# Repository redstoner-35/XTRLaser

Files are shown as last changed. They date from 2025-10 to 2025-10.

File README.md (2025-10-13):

powered by 35's Embedded Systems Inc. A Next generation Driver Solution for Portable Ultra high Output Laser Pointer                                                                                                                     

### 概述

Xtern Ripper Laser Edition(简称XTRLaser)是专用于驱动日亚LD BANK **（例如NUBB23、NUBB33以及NUBB27、NUBB37等）** 的高能效侧按电子开关控制的升压恒流驱动器。该驱动器具备自适应功能，同时支持单锂和双锂输入并自动适配采用最合适的功率驱动激光模组。该驱动的尺寸为22mm，高度7mm，可以完美兼容东东海D2GC或M0AC等22mm驱动位的侧按小直外壳。在M0AC小直内搭配日亚NUBB23模块时可以实现高达31W的峰值光功率并且稳定运行至温度保护激活。是实现小体积暴脾气亮骚烧东西激光小直的专用解决方案。相比市面上基于LED手电筒驱动的魔改产物具有更高的耐压（高达25V Rated可以适配20V工作电压的五管LD Bank） **（例如那些基于MP3431芯片单双锂输入通用升压手电驱动改反馈电阻做的LD驱动，芯片容许的最高输出电压为16V然后NUBB33类的四管激光模块的Vf高达15.98V，长期顶着芯片的输出耐压极限跑就不怕炸管么？）** 和稳定性以及更适配和更智能的温度保护和操作逻辑（一键点动烧灼模式，自动锁定等）。

### 性能数据

+ 支持的电池输入类型：1S至2S的三元锂电池组，2S电池组的总交流内阻需小于50mΩ且额定放电能力大于等于15A。 **注意：驱动在1S模式下将会自动限制输出功率至约30W避免IC过载，但是此时仍然需要使用全极耳类型的低内阻动力电池，放电能力应大于20A且交流内阻小于8mΩ。如果需要获得完整的使用体验，请搭配2S电池组使用！**
+ 支持的LD Bank类型：（单/双锂）NUBB13、NUBB23、NUBB33 **NUBB27和NUBB37硬件理论支持，但是需要调整参数请参考下方的内容** 。（仅单锂并搭配特定固件和硬件）NURM11T，具体请前往下方的LD Bank类型章节查看。
+ 支持的LD电流：150mA至4.1A（适配单管多串LD）
+ 温度保护：46度多阶变值PI环+常亮预测算法实现的自适应外壳恒温（温控启动后驱动根据外壳散热能力和环境自动调整LD的亮度达到最高可实现的亮度，充分利用外壳的散热能力和热容）+55度极亮cutoff（强制退出极亮并返回到低亮）+65度强制关机三段式温度保护。**相比那些温度一到就给你拉闸不给开机的断崖式温度保护极大提高了用户的使用体验。都5202年了还没有一个能实现自适应恒温的激光驱动，属实是扯蛋。**
+ 电池保护：具有欠压自动降档和关机保护以及过电压保护
+ 输出保护：具备LD开路和短路检测

### 输出效率

目前该驱动已进行了输出效率的初步测试，结果如下：

+ 双锂模式驱动NUBB23（全功率）：`输入：7.4V*9.5A=70.3W，输出15.99V*4.21A=67.3179W` 此时典型效率约96.01%，损耗2.98W
+ 单锂模式驱动NUBB23（半功率）：`输入：3.53V*8.90A=31.417W，输出14.93V*1.91A=28.5163W` 此时典型效率约90.76%，损耗2.90W

受限于较低的工作频率所需的4R7电感导致DCR发热损耗较大使得在单锂工作时效率不好看。不过该效率对于输出耐压支持20V LD Bank的专用22mm驱动而言仍然处于优秀水平，不需要担心在壳子内过热而无法工作。

### 自动锁定功能说明

考虑到该类激光手电具有极高的输出功率，当用户长时间静置未用，并且在某天突然拿起时会因为忘记手电处于何种状态并误开启高功率模式造成严重的安全事故。**激光贴吧之前就有因为熊孩子误拿起长期静置且未处于锁定模式的大功率激光手电并且未做任何防护的情况下意外开启造成眼睛永久失明的案例！！** 因此该驱动固件具备自动锁定功能，当手电检测到用户长时间未使用并静置超过20分钟后，驱动将会自动进入锁定模式并且重置挡位记忆到最低挡位确保安全。进入锁定模式后即使重新安装电池也无法解锁，此时用户需要参考下方章节关于按键锁的内容，手动解锁手电后手电才会恢复正常使用状态。且解锁手电后，首次单击开机时手电会固定进入低挡位以确保安全使用，用户可以自行换挡。

### 基本功能操作逻辑

+ 调焦挡位：关机状态下单击+长按进入。该挡位下驱动会令LD在远低于其阈值电流的条件下运行输出无害的弱光用于进行光学系统测试或者对焦以及瞄准工作（也可以拿来逗猫玩 *笑）。该挡位下用户可以单击关闭，若长按则会进入到循环挡位模式的最低挡位。
+ 循环挡位模式：关机状态下单击进入。首次上电时驱动默认位于最低挡位，长按在`低->中->中高->高`四个挡位内反复循环切换。单击+长按则逆向按照`高->中高->中->低`的顺序逐步降到最低并在最低挡位停止，单击关闭。**注意：如果驱动被配置为单锂电模式，则驱动的高挡位将会被禁用，此时循环只剩下：低、中和中高挡位。**
+ 无极调光模式：关机状态下长按进入。该挡位允许用户在0.4A至3A（对应0.5-22W光功率）的范围内无极调整并选定一个指定的亮度挡位（如果驱动工作在单锂模式，则调节范围将会被限制为0.4-1.8A对于0.5-12W光功率）。进入该挡位后长按升高亮度，单击+长按减少亮度。若亮度达到最高或最低时驱动会令LD慢闪提示您亮度调整已经达到限制。若要回到关机状态，则单击开关一次。 **注：该挡位的亮度数据具有永久性记忆，设定好亮度后约3秒系统会永久保存至存储器内，即使断电也不会丢失。**
+ 极亮挡位：任意状态下双击进入。如果您只安装了一节电池，则双击会进入到循环挡位中的中高档此时仍然能一键进入循环档中的最高功率（1.8A电流，对应12W光功率）模拟双击极亮的行为，**但是无法开启需要双锂的真正全功率极亮。** 如果您安装了2节电池，则此时驱动将会以全功率输出并实现约31W的光功率。 **该挡位发热巨大且输出功率极高，为了避免引起火灾请务必小心使用！**
+ 特殊功能挡位：关机状态下三击进入，长按在`SOS->呼吸巡航灯->周期频闪信标灯`这三种特殊模式内按顺序循环切换。单击+长按则逆序循环切换。单击回到关机状态。对于这三个特殊功能挡位的具体功能则如下所示：
  - SOS：驱动令LD以0.8A电流点亮播报国际标准SOS求救信号（三短三长三短）并反复循环。每次播报结束后会停顿三秒再继续。
  - 呼吸巡航灯：驱动令LD工作在呼吸闪状态（亮度从低缓升最高后又缓降到最低，到最低后熄灭并停顿三秒后再次从最低亮度缓升并反复循环）
  - 周期频闪信标灯：进入后驱动首先以低亮度点亮LD约2秒提醒用户已经进入该模式。然后驱动每隔3秒令LD以额定功率短时间脉冲工作（约50mS）后立即关闭并进入休眠，3秒后再次启动输出脉冲并反复循环。 
+ 一键烧灼模式：关机状态下四击开关，此时驱动以远低于激光管阈值电流的最低功率点亮输出无害的弱光方便用户进行瞄准，按住开关则驱动立即以全功率工作（此时约30W光功率，如果驱动工作在单锂模式则限制为约12W）进行烧灼，松开则回到低功率状态。若用户单击则回到关闭状态。该挡位具备超时和过温保护功能。若驱动电量不足或超过1分钟未操作，以及驱动发生过热事件，则会自动关机。
+ 按键锁：关机状态下五击开关，侧按指示灯红色闪三次进入锁定模式。进入锁定模式后，除了单击+长按临时开启几乎无害的低功率激光输出，松开手自动熄灭或开启20秒后自动熄灭以外（模拟人畜无害的低功率沙盘指星笔的行为，用于骗过安检），其余任何操作均会被驱动忽略并使用红色快闪5次提示用户。**为了保证安全，进入锁定模式后即使重新安装电池，激光手电也会始终保持在锁定状态。** 在锁定状态下再次五击，侧按指示灯绿色闪烁三次，并且LD以低功率点亮0.5秒表示成功解锁，此时驱动回到正常操作模式可以正常操作。

### 特殊功能操作逻辑

+ 应急求救挡位：关机状态下五击+长按进入，驱动令LD以0.6A电流点亮播报国际标准SOS求救信号（三短三长三短）并反复循环。每次播报结束后会停顿三秒再继续。该挡位只要电池在静置状态下电压高于2.5V就会持续运行并一直发送信号，可以让用户在紧急情况下以报废电池的小小代价持续的发射求救信号并获得一线生机。 **对于非紧急状态不建议使用该挡位，以免电池过度放电并永久损毁。**
+ 重置无极调光亮度：在关机状态下四击+长按，驱动将会重置无极调光亮度至最低值并进入无极调光模式，其余操作请参考基本功能章节内的无极调光操作指引。
+ 固件编译时间戳查询：关机状态下8击进入。进入后驱动将会令LD点亮1秒，提示即将开始播报。然后驱动将会按顺序播报固件编译的年份、月份，日期以及编译时的时间（精确到分钟）。首先驱动会播报固件编译的具体日期，播报会分为三组数字，每组数字之间停顿2.5秒，同一组数字之间会有1.5秒的间隔方便用户区分。在播报完第一到第三组数字所表示的驱动编译固件编译的年份、月份，日期之后，驱动将会停顿4.5秒然后开始播报固件编译的具体时间（精确到分钟）。具体编译时间的播报会分为两组数字，每组数字之间停顿2.5秒，同一组数字之间会有1.5秒的间隔方便用户区分。**需要注意的是，播报启动后就无法中断，在版本信息播报过程中，驱动将不响应任何操作，直到播报结束。** 详细的播报规则如下：
 
  - 第一组数字：指示固件编译的年份。其中LD慢速闪烁N次表示非零的数字，如果快速闪烁一次，则表示该数据位为0。两位数字之间系统会停顿1.5秒。例如`慢闪2次-停顿1.5秒-慢闪5次`表示固件编译的年份为**25（2025年）**。
  - 第二组数字：指示固件编译的月份。其中LD慢速闪烁N次表示非零的数字，如果快速闪烁一次，则表示该数据位为0。两位数字之间系统会停顿1.5秒。例如`快闪1次-停顿1.5秒-慢闪9次`表示固件编译的月份为**09（9月）**。
  - 第三组数字：指示固件编译的具体日期（精确到天）。其中LD慢速闪烁N次表示非零的数字，如果快速闪烁一次，则表示该数据位为0。两位数字之间系统会停顿1.5秒。例如`慢闪3次-停顿1.5秒-快闪1次`表示固件编译的具体日期为**30日**。
  - 第四组数字：以24小时制度指示固件编译时间的小时部分。其中LD慢速闪烁N次表示非零的数字，如果快速闪烁一次，则表示该数据位为0。两位数字之间系统会停顿1.5秒。例如`慢闪1次-停顿1.5秒-慢闪3次`表示固件编译的时间（小时）为**13时（下午1点）**。
  - 第五组数字：指示固件编译时间的分钟部分。其中LD慢速闪烁N次表示非零的数字，如果快速闪烁一次，则表示该数据位为0。两位数字之间系统会停顿1.5秒。例如`慢闪4次-停顿1.5秒-慢闪6次`表示固件编译的时间（分钟）为**46分**。

+ 设置按键有源夜光功能：关机状态下七击按键，驱动令侧按指示灯以绿色快闪一次表示功能开启。若以红色快闪一次则表示功能关闭。该功能开启后，驱动将会在闲置未用且电池电压充足的情况下令按键发出微弱绿光指示激光手电的开关位置，方便用户在全黑环境中进行操作。
+ 温度查询模式：驱动任意状态下三击+长按进入。当进入温度查询模式后激光手电的颈部开关指示灯首先将会以红黄绿依次点亮的方式（**若激光手电当前处于极寒环境使得驱动本身的温度低于0摄氏度时，先导提示将变为绿黄红的顺序**）作为先导提示，提示用户手电即将开始显示当前的内部温度（由驱动的内置的NTC热敏电阻测得）。延迟1秒后驱动将通过红色和黄色的指定次数的慢速闪烁（如果快速闪烁一次，则表示该数据位为0）提示用户当前的驱动温度。在播报完当前驱动的温度数值后，驱动将会在延迟2秒后通过后续的长亮(或者慢闪)提示用户当前驱动的具体温度值所对应的手电整体散热情况。对于温度显示的计算方式请参考如下内容：

  - 播报完毕后绿色常亮：当前手电散热良好，内部温度正常
  - 播报完毕后黄色常亮：当前手电内部温度较高，请注意防止烫手
  - 播报完毕后红色常亮：当前手电内部温度温度极高，请及时为手电散热并且避免被烫伤   
  - 驱动温度(℃)=红色闪烁次数x10+黄色闪烁次数，例如`红色慢闪4次-黄色快闪1次`表示当前驱动所测到的内部温度为40℃

+ 电池电压和电量查询功能：驱动任意状态下通过双击+长按进入。当进入电量查询模式后手电的颈部开关指示灯首先将会以红黄绿依次点亮的方式（**若电池电压低于10.00V，则系统将会切换到高精度显示模式以0.01V精度显示电量。此时先导提示将变为绿黄红的顺序**）作为先导提示，提示用户驱动即将开始显示电池电压和电量。延迟1秒后驱动将通过红色，黄色和绿色的指定次数的慢速闪烁（如果快速闪烁一次，则表示该数据位为0）提示用户当前的电池电压，播报完电池当前电压后，驱动将会在延迟2秒后通过后续的长亮(或者慢闪)提示用户当前电池电压对应的总体电量水平（指示方式参考下文中驱动位于正常工作时的指示），对于电池具体电压播报的计算方式请参考如下内容：
  
  -  99.9V显示模式：红色闪烁次数x10+黄色闪烁次数+绿色闪烁次数x0.1=当前电池电压(V)，例如`红色慢闪1次-黄色快闪1次-绿色慢闪4次`表示电池电压为10x1+0+4x0.1=10.4V。
  -  9.99V高精度显示模式：红色闪烁次数+黄色闪烁次数x0.1+绿色闪烁次数x0.01=当前电池电压(V)，例如`红色慢闪8次-黄色慢闪1次-绿色慢闪3次`表示电池电压为8+1*0.1+3x0.01=8.13V。

+ 恢复出厂设置：在驱动处于完全断电状态下（用户可以通过卸下电池并反复多次按下手电的侧按按钮直到手电没有任何反应）持续按住按钮并扭上电池包令驱动通电。此时驱动的侧部按键指示灯将会以黄色的持续高频率快闪提示用户已恢复出厂设置。用户松开按键后，驱动将会在2秒后自动重启并进入正常工作状态。

### 正常工作时的电量指示

对于电压指示，驱动在正常挡位的工作状态会通过指示灯点亮的方式提示用户当前系统的电池电量（如果驱动当前处于无保护的SOS应急求生挡位，则驱动的电量指示灯会改为每5秒短暂点亮一次以节约电力消耗）。与此同时，在驱动首次装入电池时，驱动还会通过一次持续2秒的点亮提示电池电量（指示方式和工作状态时相同）。对于驱动当前的电量状态和对应的指示灯状态请参考如下内容：

  - 绿色常亮：电池电量充足
  - 黄色常亮：电池电量较为充足
  - 红色常亮：电池电量不足，请尽快为电池充电
  - 红色慢闪：电池电量严重不足，请立即为电池充电（此时驱动的功能将会被限制）

与此同时，在驱动正常工作时，驱动还会再某些特定事件发生时通过一定时间内的短时间熄灭次数的循环指示驱动发生的事件，详细的事件列表如下：

  + 每2秒瞬时熄灭1次：驱动检测到外壳温度过高，驱动已启用温控限制驱动输出功率避免LD过热光衰

### 电池参数配置

该激光驱动同时支持单锂和双锂电的操作，驱动可以自动检测双锂电的插入并切换为双锂电池模式，驱动在单锂电模式下仍然可以工作但是部分功能将会被限制以避免电池过载，为了得到最佳的使用体验建议安装两节电池。对于电池配置模式用户也可以随时进行手动调整。对于如何确认系统当前的电池配置以及调整配置等，请参考如下内容：

+ 识别系统当前的电池配置：在每次装入电池时，电量指示灯会进行自检并显示当前电池电量。如果当前系统开启了双锂电模式，则系统在装入电池后首先会以黄色快闪2次，延迟0.5秒后再显示电池电量（假设电量充足，则指示灯将绿色常亮3秒）。若当前为单锂模式，则驱动将会直接提示电池电量。
+ 双锂电自动识别功能：当系统处于单锂电模式时，如果用户装入两节电池，则系统会检测到并自动切换至双锂模式。此时系统会通过令侧按指示灯绿色快速频闪2次作为检测到双锂的提示。此时驱动将会自动切换到双锂状态。
+ 切换单锂/双锂模式：对于非红光模式的固件，用户可以通过在关机状态下六击侧按切换单锂和双锂模式。当切换为单锂模式时，激光手电的侧按将会通过红色频闪一次提示已经成功切换。如果是切换为双锂模式，则激光手电的侧按将会通过绿色频闪2次提示成功切换。**需要注意的是，如果系统当前安装了2节电池，为了保护电池避免过度放电，此时系统将会禁止用户切换为单节锂电池模式。如果您需要从双锂模式切换至单锂模式，请将电池取出并仅安装一节电池，再进行切换操作。**

### 针对五光束阵列管（如NUBB37/38/27/28T）的硬件适配操作

该驱动硬件原生适配四光束的日亚阵列管，但是经过改造后即可适配五光束的阵列管。改造的具体操作如下：

+ 将驱动的输出电压设定电阻 `R1` 由原来的470K更换到560K。此时驱动的输出开路电压将会提高至21.1V。
+ 将驱动的1206输出主滤波电容C4 C5（1206 47uF 25V）由原来的只焊一个改为垂直方向叠焊两个，增加输出电容的有效容量。
+ 将驱动的环路补偿Rc电阻 `R4` 由原来的10K改为9.1K降低环路速度避免震荡。

### LD模式选择

该固件的源码支持多种不同的LD模块。用户在编译时需要在工程的宏定义中指定LD的类型，否则编译无法通过。目前该固件支持的LD列表可以参考如下内容。如果您需要针对特定型号的LD进行适配，则请自行测试或提供LD样品给作者并进行标定。

+ NUBB13/NUBB23/NUBB33:单发光体四串四光束蓝光模组，可以直接使用。编译时使用`USING_LD_NUBB33`宏。
+ NUBB14/NUBB24/NUBB34:双发光体四串八光束蓝光模组，里面实际上等效于两个NUBB13/NUBB23/NUBB33模块安装在同一个基板，可以把单管拆下来使用。编译时使用`USING_LD_NUBB33`宏。
+ NUBB27/NUBB37:单发光体五串五光束蓝光模组，需要搭配硬件调整方可使用。编译时使用`USING_LD_NUBB37`宏。
+ NUBB28T/NUBB38:双发光体五串十光束蓝光模组，里面实际上等效于两个NUBB27/NUBB37模块安装在同一个基板，可以把单管拆下来并搭配硬件调整使用。编译时使用`USING_LD_NUBB37`宏。
+ NURM11T：单发光体四串四光束红色光模组，可以直接使用， **但是该模组因工作电压较低，仅支持单锂模式且需要对硬件进行调整！** 编译时使用`USING_LD_NURM11T`宏。

### 编译固件时MCU的CONFIG配置

由于中微单片机内部有一组硬编码于Flash指定区域，用于设置单片机的硬件首选项（例如看门狗，调试模式，低电压保护点等）的配置Word。为了确保编译出来的固件可以在硬件内正常运行，您需要在工程配置(Options for Target 'XTRLaser'->Debug选项卡->右上角的Settings按钮)的Config设置菜单，按照下表正确填写MCU的配置。错误的CONFIG设置会引起固件工作异常！

+ Power                      :  Inter 3.3V            
+ WDT                        :  SOFTWARECONTROL     
+ PROTECT                    :  ENABLE              
+ FLASH_DATA_PROTECT         :  ENABLE              
+ LVR                        :  1.8V                
+ DEBUG                      :  Disable             
+ OSC                        :  HSI                 
+ OSC_PRESCALE               :  Fosc/1              
+ HSI_FS                     :  Fhsi/1              
+ EXT_RESET                  :  DISABLE             
+ EXT_RESETSEL               :  P00                 
+ WAKEUP_WAITTIME            :  500us               
+ CPU_WAITCLOCK              :  2T                  
+ WRITE_PROTECT[0-2K]        :  DISABLE             
+ WRITE_PROTECT[2-4K]        :  DISABLE             
+ WRITE_PROTECT[4-6K]        :  DISABLE             
+ WRITE_PROTECT[6-8K]        :  DISABLE             
+ WRITE_PROTECT[8-10K]       :  DISABLE             
+ WRITE_PROTECT[10-12K]      :  DISABLE             
+ WRITE_PROTECT[12-14K]      :  DISABLE             
+ WRITE_PROTECT[14-16K]      :  DISABLE             
+ BOOT                       :  BOOT_DIS 

### 运行时错误监测和错误ID汇报

该驱动具备错误监视系统，如果在运行期间如果驱动检测到无法解决的致命问题则会进入保护模式避免驱动和昂贵的激光二极管损毁，并通过颈部侧按键的指示灯提示用户发生的错误类型。每个指示循环首先以红黄绿的颜色切换闪烁开始，然后通过紧跟着的红色慢闪次数指示错误ID号，慢闪结束后会停顿一会并重新开始循环，对于ID号所对应的错误描述请参考如下内容：

+ 闪烁1次(Fault_DCDCFailedToStart) 驱动在尝试启动DCDC时失败。检查驱动输出正极是否对外壳短路，DCDC芯片的使能信号和内部LDO输出电压是否正常。
+ 闪烁2次(Fault_DCDCShort) 驱动在运行时检测到输出短路。
+ 闪烁3次(Fault_InputOVP) 驱动检测到输入电压过高，请检测驱动的电池配置是否和使用的电池配套。
+ 闪烁4次(Fault_DCDCOpen) 驱动在运行时检测到输出空载，请检查LED是否损坏。
+ 闪烁5次(Fault_NTCFailed) 驱动在运行期间检测到测量驱动温度的热敏电阻出现异常，检查热敏电阻和测温部分的上拉电阻是否损坏。
+ 闪烁6次(Fault_OverHeat) 驱动检测到外壳温度过高，请等待手电冷却。冷却后故障会自动解除

----------------------------------------------------------------------------------------------------------------------------------
© redstoner_35 @ 35's Embedded Systems Inc.  2025

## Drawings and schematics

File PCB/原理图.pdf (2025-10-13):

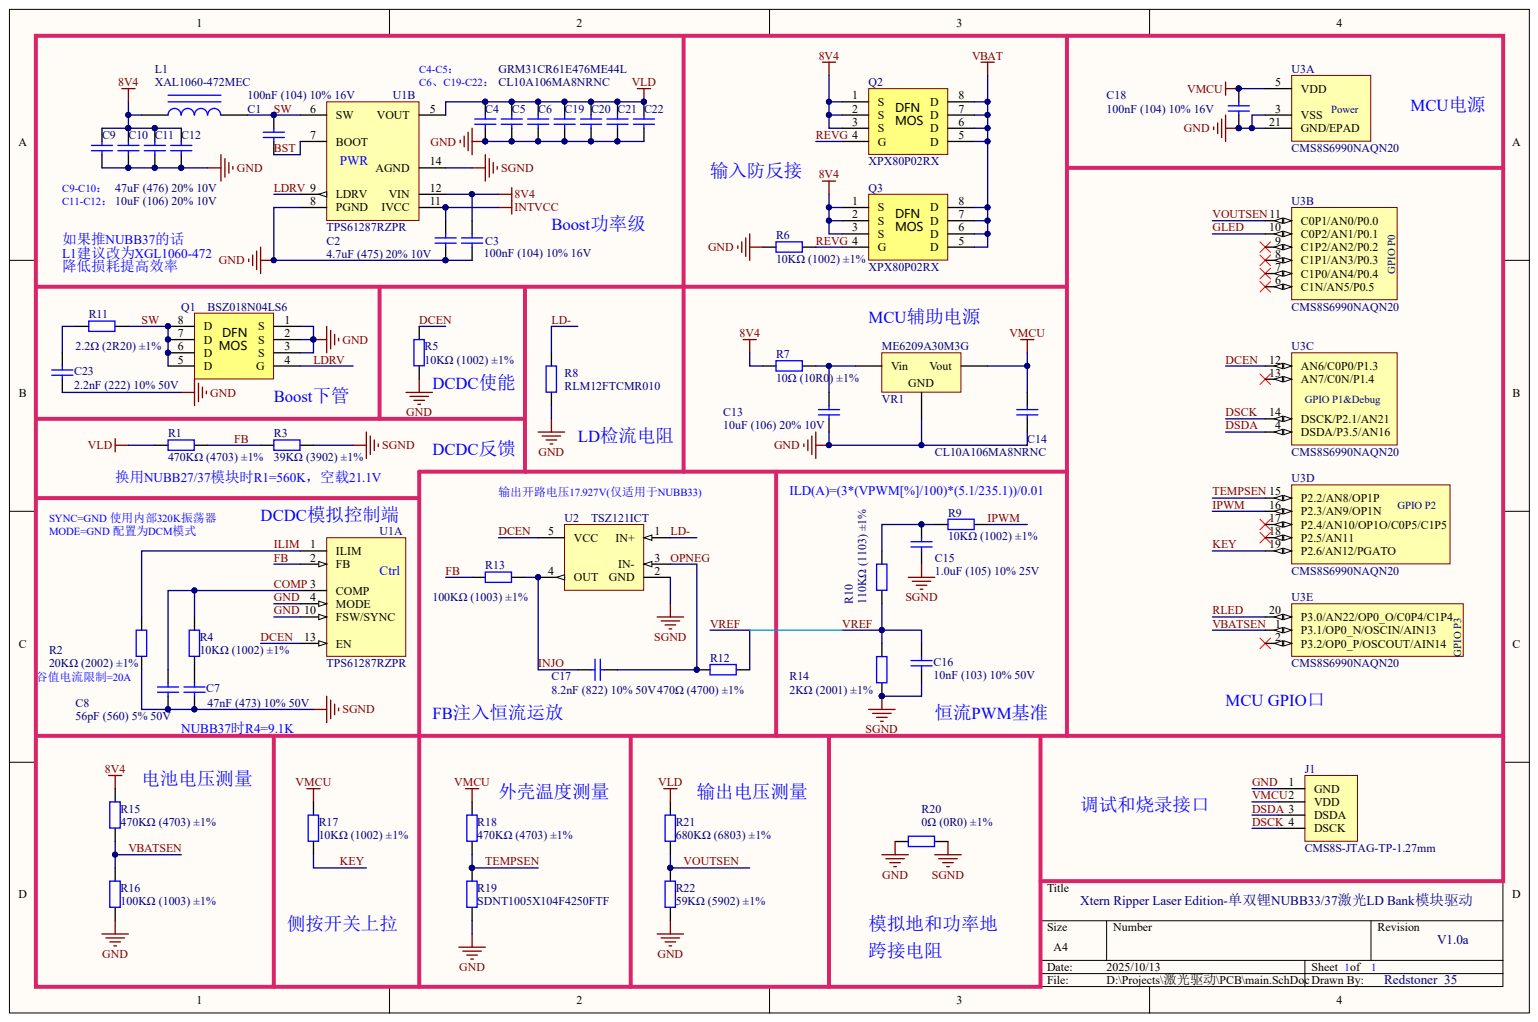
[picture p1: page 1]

Title
Xtern Ripper Laser Edition-单双锂NUBB33/37激光LD Bank模块驱动

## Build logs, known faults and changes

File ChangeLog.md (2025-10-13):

# 更新日志

## [1.1.0.1] - OCT-13-2025 18:31

**孩子们，喜闻乐见的五管大怪物NUBB37的硬件支持方案他终于来了！**

### 驱动固件勘误

+ 修复驱动在锁定模式时，单击+长按开启弱光输出的功能在开启5秒后自动调整至异常的最低亮度且无法关闭的bug
+ 修复驱动在锁定模式装入电池时，不显示电池当前电量的bug

### 驱动固件更新

+ 调整固件编译时间戳至`20251013-1831`
+ 修改驱动在NUBB37模式的极亮输出电流至4000mA(双锂模式)以及1600mA(单锂模式)
+ 针对NUBB37的高电压配合硬件模块的更新修改输出电压的ADC遥测参数
+ 针对硬件PWMDAC的参数变动调整输出通道模块的参数配置
+ 调整驱动的电池电量报告逻辑新增根据输出电流动态计算阈值的功能解决极亮错误黄灯

### 硬件勘误

+ 修改驱动的恒流环路补偿电容C17的参数，降低驱动在弱光挡位开启时的过冲。

### 硬件更新

+ 更改PWMDAC模块的分压电阻（R10和R14）配比，由原来的220K比5.1K更改为110K比2K，降低PWMDAC输出阻抗。
+ 调整输出电压检测电阻（R22）为59K增加输出电压检测量程，适配五管模块的高电压。
+ 在原理图内增加NUBB37管子所需的硬件改动的说明文字

### 其余更新

+ changelog新增硬件更新内容条目
+ 更新readme增加NUBB37五管阵列的硬件改造说明
+ 修正readme内部分书写和描述错误

## [1.1.0.0] - OCT-06-2025 16:59

### 驱动固件勘误

本次没有驱动固件勘误内容

### 驱动固件更新

+ 调整固件编译时间戳至`20251006-1656`
+ 增加默认开启的20分钟无操作自动锁定的安全功能避免以外事故发生
+ 驱动循环挡位逻辑调整，驱动会根据当前电压实时禁用/启用循环档内的挡位并自动调整循环
+ 对驱动固件的每个C源文件增加了该源码文件的文件头和功能描述信息
+ 修改WUT定时器的初始化逻辑，新增针对WUT定时器部分的自动计数器值计算（根据时间参数计算）
+ 修改驱动欠压WUT定时器的唤醒间隔至8000mS，针对新的自动锁定功能做适配。

### 硬件勘误

本次没有硬件勘误内容

### 其余更新

+ 更新readme增加驱动实测的效率数据
+ 更新readme增加驱动新增的自动锁定功能的描述
+ 修正readme内部分书写和描述错误

## [1.0.0.3] - SEP-30-2025 20:16

### 驱动固件勘误

+ 修复特殊模式下低电量提示闪烁导致特殊功能挡位工作异常的问题
+ 修复固件根据LD类型宏自动调整固件配置的宏处理模块工作异常导致编译无法通过的问题
+ 修改固件的option byte内的低压复位点至1.8V，解决单锂电模式下电池电量接近耗尽时系统因启动时瞬时压降导致单片机反复重启无法开启的bug
+ 对固件输出通道模块的矫正电流系数和驱动各挡位的电流配置进行调整解决输出电流偏高的问题。

### 驱动固件更新

+ 调整固件编译时间戳至`20250930-2016`
+ 新增没有低电压保护功能的应急求救用SOS挡位用于户外求生
+ 调整电量指示灯驱动部分的代码，针对应急求救挡位需要关闭电量指示节约电量的功能做适配
+ 增加锁定模式下模拟低功率沙盘指示激光笔的低功率点动输出功能（单击+长按开启低功率输出，松手即熄灭）方便通过安检。
+ 修改巡航呼吸闪和信标脉冲闪的电流至3.1A
+ 修改高亮挡位的电流至2.7A获得更大的挡位电流差距

### 硬件勘误

本次没有硬件勘误内容

### 其余更新

+ 更新readme增加应急求救SOS挡位的功能描述
+ 更新readme增加锁定模式下模拟低功率沙盘指示激光笔的低功率点动输出功能的描述
+ 修改针对NUBB33激光管的预编译固件名称至[XTRLaser_NUBB33.hex](/Firmware/XTRLaser_NUBB33.hex)
+ 新增针对NUBB37激光管的[预编译固件](/Firmware/XTRLaser_NUBB37.hex) **注意：该固件需要特殊的硬件适配，目前硬件暂未给出支持方案，请等待后续更新**

## [1.0.0.2] - SEP-30-2025 11:18

### 驱动固件勘误

+ 修复系统锁定模式下极亮挡位仍然异常生效的bug

### 驱动固件更新

+ 调整固件编译时间戳至`20250930-1119`
+ 新增根据最大电流自适应计算巡航呼吸闪电流斜率的功能，实现电流斜率在单双锂模式下一致
+ 新增根据定义的LD类型自动决定双锂极亮和单锂最大功率的自动定义模块
+ 修改固件的option byte内的低压复位点提高复位电压至2.5V，进一步避免饿死电池

### 硬件勘误

本次没有硬件勘误内容

### 其余更新

+ 更新readme新增固件编译的LD类型选择定义
+ 修正readme内部分书写和描述错误
+ 调整极亮挡位功能的描述，增加在单锂模式下双击尝试进入极亮挡位时驱动的行为描述

## [1.0.0.1] - SEP-29-2025 14:58

### 驱动固件勘误

+ 修正一键灼烧模式超时功能异常导致开启后即使有操作一分钟后也会强制关闭的bug

### 驱动固件更新

+ 调整固件编译时间戳至`20250929-1458`
+ 新增LD类型和固件参数配置的自动定义模块，软件层面支持多种LD(硬件层面待适配)

### 硬件勘误

本次没有硬件勘误内容

### 其余更新

+ 修改预编译固件名称至[XTRLaser_NUBM33.hex](/Firmware/XTRLaser_NUBM33.hex)

## [1.0.0.0] - SEP-29-2025 12:36

### 驱动固件勘误

本次没有驱动固件勘误内容

### 驱动固件更新

+ 初始分支首次提交固件源代码

### 硬件勘误

本次没有硬件勘误内容

### 其余更新

+ 初始分支首次提交初始版PCB文件（包括驱动主PCB和侧按PCB）

----------------------------------------------------------------------------------------------------------------------------------
© redstoner_35 @ 35's Embedded Systems Inc.  2025

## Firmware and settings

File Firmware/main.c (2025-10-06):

/****************************************************************************/
/** \file main.c
/** \Author redstoner_35
/** \Project Xtern Ripper Laser Edition 
/** \Description 这个文件负责系统的主函数处理

**	History: Initial Release
**	
*****************************************************************************/
/****************************************************************************/
/*	include files
*****************************************************************************/
#include "cms8s6990.h"
#include "GPIO.h"
#include "delay.h"
#include "SideKey.h"
#include "LEDMgmt.h"
#include "ADCCfg.h"
#include "PWMCfg.h"
#include "LVDCtrl.h"
#include "SysReset.h"
#include "LowVoltProt.h"
#include "TempControl.h"
#include "BattDisplay.h"
#include "OutputChannel.h"
#include "SelfTest.h"
#include "SOS.h"
#include "BreathMode.h"
#include "Beacon.h"

/****************************************************************************/
/*	Local variable  definitions('static')
****************************************************************************/
bit TaskSel=0;  //选择处理的系统任务

/****************************************************************************/
/*	External Function prototypes definition
****************************************************************************/
void SleepMgmt(void);
void MaskUnusedIO(void);

//主函数
void main()
	{
	//时钟和RSTCU初始化	
	ClearSoftwareResetFlag();
	LVD_Disable(); 				 //启动系统前每次确保WUT处于一个已知状态
  StartSystemTimeBase(); //启动系统定时器提供系统定时和延时函数
	//初始化外设
	ADC_Init(); //初始化ADC
	PWM_Init(); //启动PWM定时器
	LED_Init(); //初始化侧按LED
  SideKeyInit(); //侧按初始化	
	OutputChannel_Init(); //输出初始化	
	ModeFSMInit(); //初始化模式状态机
  DisplayVBattAtStart(1); //显示电池状况
	MaskUnusedIO();   //屏蔽掉所有单片机未使用的IO降低待机功耗
	EnableADCAsync(); //启动ADC的异步模式提高处理速度
	//主循环	
  while(1)
		{
	  //实时处理
		SystemTelemHandler();
		BatteryTelemHandler(); //获取ADC和电池信息	
		SideKey_LogicHandler(); //处理侧按事务
		ThermalMgmtProcess(); //温度管理
		ModeSwitchFSM(); //挡位状态机
		OutputChannel_Calc();  //输出通道处理
		PWM_OutputCtrlHandler(); //处理PWM输出事务	
		//8Hz交错定时处理
		if(!SysHFBitFlag)continue; //时间没到，跳过处理
			
		//Task0，处理计算量比较大的任务
    if(!TaskSel)
			{
			LEDControlHandler();//侧按指示LED控制函数	
			BattAlertTIMHandler(); //电池警报定时处理
			OutputFaultDetect(); //输出故障检测
			ThermalPILoopCalc(); 				//积分器计算	
			ShowEntered2SModeProc(); //处理进入2S模式的显示
			SleepMgmt(); //睡眠处理
			BreathFSM_TIMHandler(); //呼吸模式状态机计时处理
			
			//处理结束，对任务选择进行翻转处理下一组
			TaskSel=1;
		  }			
		//Task1，处理计算量比较小的计时任务
		else
			{	
			SideKey_TIM_Callback();//侧按按键的监测定时器处理		
			BattDisplayTIM(); //电池电量显示TIM
			DisplayErrorTIMHandler(); //故障代码显示
			ModeFSMTIMHandler(); //模式状态机处理
			HoldSwitchGearCmdHandler(); //长按换挡处理
			SOSTIMHandler(); //SOS定时器
			RuntimeUpdateTo2S(); //动态检测电池电压并更新到2S
			BeaconFSM_TIMHandler(); //信标计时器
				
			//处理结束，对任务选择进行翻转处理下一组
			TaskSel=0;
			}
		//处理完毕，令flag清零
		SysHFBitFlag=0;	
		}
	}

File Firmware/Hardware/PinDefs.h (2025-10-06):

/************************************************************************************/
/** \file PinDefs.h
/** \Author redstoner_35
/** \Project Xtern Ripper Laser Edition 
/** \Description 这个文件为底层的硬件定义文件，定义了整个工程内所有外设对应的硬件PIN和模
拟输入ADC通道的映射关系。

**	History: Initial Release
**	
/************************************************************************************/
#ifndef PINDEFS
#define PINDEFS
/************************************************************************************/
/* Include files */
/************************************************************************************/
#include "GPIOCfg.h"

/************************************************************************************
以下是系统的常规GPIO引脚，用于控制外部外设切换功能
************************************************************************************/
#define DCDCENIOP GPIO_PORT_1
#define DCDCENIOG 1
#define DCDCENIOx GPIO_PIN_3 //LD的DCDC电源使能引脚(P1.3)

/************************************************************************************
以下是系统的PWM输出引脚，用于对外输出PWM控制风扇速度，DCDC输出电压等等
************************************************************************************/
#define PWMIOP GPIO_PORT_2
#define PWMIOG 2
#define PWMIOx GPIO_PIN_3  //负责控制恒流基准DAC的输出引脚（P2.3）

/************************************************************************************
以下是系统的模拟输入引脚，例如电池电压测量等
************************************************************************************/
#define NTCInputIOG 2
#define NTCInputIOx GPIO_PIN_2 
#define NTCInputAIN 8						//NTC输入(P2.2,AN8)

#define VOUTFBIOG 0
#define VOUTFBIOx GPIO_PIN_0
#define VOUTFBAIN 0						//输出电压反馈引脚(P0.0,AN0)

#define VBATInputIOG 3
#define VBATInputIOx GPIO_PIN_1
#define VBATInputAIN 13					//电池电压检测引脚(P3.1,AN13)

/************************************************************************************
以下是系统的按键模块的GPIO引脚，负责驱动负责按键小板部分(包括指示灯和按键本身) 
************************************************************************************/
#define SideKeyGPIOP GPIO_PORT_2
#define SideKeyGPIOG 2
#define SideKeyGPIOx GPIO_PIN_6 	//侧按按键(P2.6)


#define RedLEDIOP GPIO_PORT_3
#define RedLEDIOG 3
#define RedLEDIOx GPIO_PIN_0		//红色指示灯(P3.0)	


#define GreenLEDIOP GPIO_PORT_0
#define GreenLEDIOG 0
#define GreenLEDIOx GPIO_PIN_1		//绿色指示灯(P0.1)

#endif /* PINDEFS */

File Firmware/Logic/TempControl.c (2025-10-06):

/****************************************************************************/
/** \file TempControl.c
/** \Author redstoner_35
/** \Project Xtern Ripper Laser Edition 
/** \Description 这个文件是顶层应用层文件，负责根据系统温度动态调整输出功率在最大
限度利用外壳散热能力的同时避免系统过热。

**	History: Initial Release
**	
*****************************************************************************/
/****************************************************************************/
/*	include files
*****************************************************************************/
#include "ADCCfg.h"
#include "LEDMgmt.h"
#include "delay.h"
#include "ModeControl.h"
#include "TempControl.h"
#include "BattDisplay.h"
#include "OutputChannel.h"
#include "PWMCfg.h"
#include "LowVoltProt.h"
#include "SelfTest.h"
#include "FastOp.h"

/****************************************************************************/
/*	Local pre-processor symbols/macros('#define')
****************************************************************************/

//PI环参数和最小电流限制
#define ILEDRecoveryTime 120 //使用积分器缓慢升档的判断时长，如果积分器持续累加到这个时长，则执行一次调节(单位秒)
#define SlowStepDownTime 60 //使用积分器缓慢降档的判断时长，如果积分器持续累加到这个时长，则执行一次调节(单位秒)
#define IntegralCurrentTrimValue 2500 //积分器针对输出的电流修调的最大值(mA)
#define IntegralFactor 12 //积分系数(每单位=1/8秒，越大时间常数越高，6=每分钟进行40mA的调整)
#define MinumumILED 390 //降档系统所能达到的最低电流(mA)

//常亮电流配置
#define ILEDConstant 750 //降档系统内温控的常亮电流设置(mA)
#define ILEDConstantFoldback 500 //在接近温度极限时的降档系统内的常亮电流设置(mA)

//温度配置
#define ForceOffTemp 65 //过热关机温度
#define ForceDisableTurboTemp 50 //超过此温度无法进入极亮
#define ConstantTemperature 46 //非极亮挡位温控启动后维持的温度
#define ReleaseTemperature 35 //温控释放的温度
#define LeaveTurboTemperature ForceOffTemp-10   //退出极亮温度为关机保护温度-10

/*   积分器满量程自动定义，切勿修改！    */
#define IntegrateFullScale IntegralCurrentTrimValue*IntegralFactor

#if (IntegrateFullScale > 32000)
	//算出的积分器量程大于32000，非法值
	#error "Error 001:Invalid Integral Configuration,Trim Value or time-factor out of range!"
#endif

#if (IntegrateFullScale <= 0)
	//算出的积分器量程为0值，报错
	#error "Error 002:Invalid Integral Configuration,Trim Value or time-factor must not be zero or less than zero!"
#endif
/****************************************************************************/
/*	Global variable definitions(declared in header file with 'extern')
****************************************************************************/

bit IsPauseStepDownCalc; //是否暂停温控的计算流程（该bit=1不会强制复位整个温控系统，但是会暂停计算）
bit IsDisableTurbo;  //禁止再度进入到极亮档
bit IsForceLeaveTurbo; //是否强制离开极亮档

/****************************************************************************/
/*	Local type definitions('typedef')
****************************************************************************/

/****************************************************************************/
/*	Local variable  definitions('static')
****************************************************************************/
//内部变量
static xdata int TempIntegral;
static xdata int TempProtBuf;
static xdata unsigned char StepUpLockTIM; //计时器

//内部状态位
static bit IsNearThermalFoldBack; //标记位，是否接近于退出极亮温度
static bit IsThermalStepDown; //标记位，是否降档
static bit IsTempLIMActive;  //温控是否已经启动
static bit IsSystemShutDown; //是否触发温控强制关机

/****************************************************************************/
/*	Function implementation - local('static')
****************************************************************************/

static void ThermalIntegralHandler(bool IsStepDown,bool IsEnableFastAdj)	//温控系统中积分追踪温度变化实现恒亮的处理
	{
	int Buf;
	//条件定义，如果积分值小于上限且系统需要快速调整，则令积分器以和温度挂钩的可变速率工作
	#define IsEnableQuickItg (abs(TempIntegral)<(IntegrateFullScale-Buf)&&IsEnableFastAdj)
	//计算温度差和积分数值
	if(IsStepDown)Buf=Data.Systemp-(LeaveTurboTemperature-8);
	else Buf=(ReleaseTemperature+5)-Data.Systemp; //降档模式下系统温度误差值为强制极亮的温度-8，升档模式为恢复温度+5
	if(IsNegative16(Buf))Buf=0; //温度差不能为负数
	//进行积分器本次调整值的计算
	if(IsEnableQuickItg)Buf<<=1;      //快速调整开启,令调整值=温差*2
	else Buf=0;
	Buf++;  													//这里需要保证Buf始终为1(快速调整被禁用后调整值将会变为0)确保积分器正常响应
  //应用积分数值到积分缓存
	TempIntegral+=(IsStepDown?Buf:-Buf);
	#undef IsEnableQuickItg            //这个宏定义只是该函数的局部定义，需要在函数末尾禁用掉避免后续意外使用到导致问题
	}
	
//系统低于常亮电流，进入积分器缓慢追踪系统温度的时候把超过积分器量程的部分push到比例器去，腾出积分器并继续追踪的模块
static void ThermalIntegralCommitToProtHandler(void)	
	{
	//当前积分器累计的参数小于复位时间，退出
	if(abs(TempIntegral)<(ILEDRecoveryTime*8))return;
	//将积分器内累积的变化成比例应用到比例项并清零积分器
	TempProtBuf+=TempIntegral/IntegralFactor;
	TempIntegral=0;						
	}

//负责温度使能控制的施密特触发器
static bit TempSchmittTrigger(bit ValueIN,char HighThreshold,char LowThreshold)	
	{
	if(Data.Systemp>HighThreshold)return 1;
	if(Data.Systemp<LowThreshold)return 0;
	//数值保持，没有改变
	return ValueIN;
	}

/****************************************************************************/
/*	Function implementation - global ('extern')
****************************************************************************/

bit QueryIsThermalStepDown(void)	//获取系统是否触发降档
	{
	//当前处于电量显示状态不允许打断降档提示
	if(VshowFSMState!=BattVdis_Waiting)return 0; 
	//返回提示标志位
	return IsThermalStepDown;
	}

//换挡的时候根据当前恒温的电流重新PI值
void RecalcPILoop(int LastCurrent)	
	{
	int buf,ModeCur;
	//目标挡位不需要计算,复位比例缓存
	if(!CurrentMode->IsNeedStepDown)TempProtBuf=0;
	//需要复位，执行对应处理
	else
		{	
		//获取当前挡位电流
		ModeCur=QueryCurrentGearILED();
		//计算P值缓存
		buf=TempProtBuf+(TempIntegral/IntegralFactor); //计算电流扣减值
		if(IsNegative16(buf))buf=0; //电流扣减值不能小于0
		buf=LastCurrent-buf; //旧挡位电流减去扣减值得到实际电流(mA)
		TempProtBuf=ModeCur-LastCurrent; //P值缓存等于新挡位的电流-旧挡位实际电流(mA)
		if(IsNegative16(TempProtBuf))TempProtBuf=0; //不允许比例缓存小于0
		}
	//清除积分器缓存
	TempIntegral=0;
	}
	
//输出当前温控的限流值
int ThermalILIMCalc(void)
	{
	int result;
	//判断温控是否需要进行计算
	if(!IsTempLIMActive)
		{
		result=Current; 				//温控被关闭，电流限制进来多少返回去多少
		IsThermalStepDown=0;  	//指示温控已被关闭
		}
	//开始温控计算
	else
		{
		result=TempProtBuf+(TempIntegral/IntegralFactor); //根据缓存计算结果
		if(IsNegative16(result))result=0; //不允许负值出现
		result=Current-result; //计算限流值结果
		if(result<MinumumILED) //已经调到底了，禁止PID继续累加
			{
		  TempProtBuf=Current-MinumumILED; //将比例输出结果限幅为最小电流
		  TempIntegral=0;
		  result=MinumumILED; //电流限制不允许小于最低电流
			}
    //判断温控是否已经触发			
		if(result<(Current-200))IsThermalStepDown=1;	//温控已经让输出电流下调200mA，提示温控触发
		}
	//返回结果	                               
	return result; 
	}
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

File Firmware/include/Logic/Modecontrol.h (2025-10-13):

#ifndef _ModeControl_
#define _ModeControl_

#include "stdbool.h"
#include "FastOp.h"

typedef enum
	{
	LVPROT_Disable=0,  //该挡位关闭低电量保护
	LVPROT_Enable_Jump=1, //该挡位低电量保护开启，当电量低于阈值后执行跳档
	LVPROT_Enable_OFF=2		//该挡位低电量保护开启，当电量低于阈值后立即执行关机
	}LVProtectTypeDef;	
	
typedef struct
	{
	int RampCurrent;
	int RampBattThres;
	int RampCurrentLimit;
	unsigned char RampLimitReachDisplayTIM;
	unsigned char CfgSavedTIM;
	}SysConfigDef;	
	
typedef enum
	{
	Mode_OFF=0, //关机
	Mode_Fault=1, //出现错误
	//无极调光
	Mode_Ramp=2, //无极调光
	//正常阶梯挡位
	Mode_Low=3, //低亮
	Mode_Mid=4, //中亮
	Mode_MHigh=5,   //中高亮
	Mode_High=6,   //高亮
	//特殊挡位
	Mode_Turbo=7, //极亮
	Mode_SOS=8, //SOS
	Mode_Focus=9, //对焦专用档
	Mode_Burn=10, //烧东西专用档
	Mode_Breath=11, //呼吸模式
	Mode_Beacon=12,  //间歇闪模式
	Mode_SOS_NoProt=13 //无保护SOS模式
	}ModeIdxDef;
	

typedef struct
	{
  ModeIdxDef ModeIdx;
  int Current; //挡位电流(mA)
	int MinCurrent; //最小电流(mA)，仅无极调光需要
	int LowVoltThres; //低电压检测电压(mV)
	bool IsModeHasMemory; //是否带记忆
	bool IsNeedStepDown; //是否需要降档
	//是否允许进入极亮和爆闪
	bool IsEnterTurboStrobe; 
	//低电量保护设置
  ModeIdxDef ModeWhenLVAutoFall;		//低电量触发保护之后，如果不执行关机则自动跳转的挡位
	LVProtectTypeDef LVConfig;        //低电量保护机制的类型
	//挡位切换设置
  ModeIdxDef ModeTargetWhenH;
	ModeIdxDef ModeTargetWhen1H;	 //模式挡位切换设置，长按和单击+长按切换到的目标挡位
	}ModeStrDef; 

//外部引用
extern xdata unsigned char DisplayLockedTIM; //锁定提示计时器
extern ModeStrDef *CurrentMode; //当前模式结构体
extern xdata ModeIdxDef LastMode; //上一个挡位	
extern xdata SysConfigDef SysCfg; //无极调光配置	
extern bit IsSystemLocked;		//系统是否已锁定
extern bit IsEnableIdleLED;	//是否开启待机提示	
extern bit IsEnable2SMode;    //是否开启双锂模式
	
/************************************************
根据LD激光最高输出电流的自动定义，该函数决定系统的
最大功率限制，为了确保激光驱动正常工作，不得擅自
修改或调整！！！	
************************************************/	
#ifdef USING_LD_NUBB33
	
	//使用NUBB13/23/33 四管455nm LD
	#define SingleCellModeICCMAX 1900
	#define DualCellTurboCurrent 4250

#elif defined(USING_LD_NUBB37) 

	//使用NUBB27/37 五管455nm LD	
	#define SingleCellModeICCMAX 1600
	#define DualCellTurboCurrent 4000
	
#elif defined(USING_LD_NURM11T)
	
	//使用NURM11T 四管双束638nm LD
	#define SingleCellModeICCMAX 1800
	#define DualCellTurboCurrent 3500
	
#else

	//其余LD类型默认按照1.6A来
	#define SingleCellModeICCMAX 1600
	#define DualCellTurboCurrent 3500
	
#endif

//特殊宏定义
#define QueryCurrentGearILED() CurrentMode->Current //获取当前挡位的电流函数
#define ModeTotalDepth 14 //系统一共有几个挡位			
	
//函数
ModeStrDef *FindTargetMode(ModeIdxDef Mode,bool *IsResultOK);//输入指定的Index，从index里面找到目标模式结构体并返回指针
void ModeFSMTIMHandler(void);//挡位状态机所需的软件定时器处理
void ModeSwitchFSM();//挡位状态机
void SwitchToGear(ModeIdxDef TargetMode);//换到指定挡位
void ReturnToOFFState(void);//关机	
void HoldSwitchGearCmdHandler(void); //换挡间隔生成	
void ModeFSMInit(void); //初始化状态机	

#endif

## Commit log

2025-09-29 V1.0.0.1小幅度版本更新，更改内容请查看changelog
2025-09-30 V1.0.0.2版本更新，详情请查看changelog
2025-09-30 V1.0.0.3版本更新，详情请查看changelog
2025-10-06 V1.1.0.0大幅度版本更新，详情请查看ChangeLog
2025-10-13 V1.1.0.1针对NUBB37的版本更新，详情请查看changelog
    [NUBB23驱动.PrjPcb, PCB2.PcbDoc, main.SchDoc]
